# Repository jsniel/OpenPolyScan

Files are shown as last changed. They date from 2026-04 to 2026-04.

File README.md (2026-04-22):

# OpenPolyScan

OpenPolyScan est un prototype open source de reconnaissance de plastiques à bas coût,
conçu pour des usages en fablabs, ateliers, médiation, recherche-action et expérimentation locale.

Le projet repose sur :
- un capteur multispectral **AS7265x**
- une carte **ESP32** pour l’acquisition et l’export des mesures
- un jeu de données spectral
- des scripts Python de classification par apprentissage automatique

---

## Origine du projet

OpenPolyScan a été initié au sein de **L’Atelier Autonome** dans le cadre d’un projet de
recyclage local du plastique inspiré de Precious Plastic, soutenu par l’ADEME dans l’appel
à projets « Low-tech en territoire normand ».

Il est publié en open source afin d’en assurer la continuité et la diffusion.
Le projet est désormais maintenu par **Jean-Sébastien Niel**.

L’objectif était de développer un appareil simple et accessible d’identification des plastiques
pour des structures comme les fablabs et ateliers citoyens.

---

## Objectifs

- rendre visible et compréhensible l’analyse spectrale des plastiques  
- proposer une base reproductible à faible coût  
- documenter un prototype technique ouvert  
- ouvrir la voie à une base de données collaborative de signatures spectrales  
- permettre à d’autres ateliers, chercheurs ou structures pédagogiques d’améliorer le projet  

---

## Contenu du dépôt

- `firmware/` : code ESP32 pour l’acquisition et l’export CSV  
- `scripts/` : scripts Python d’entraînement et d’évaluation  
- `data/` : jeux de données spectrales d’exemple  
- `hardware/` : fichiers CAO et STL du support / boîtier  
- `docs/` : documentation technique et méthodologique  
- `models/` : emplacement pour les modèles entraînés  
- `examples/` : exemples d’utilisation  

---

## État du projet

OpenPolyScan est un **prototype expérimental**.

Le système permet :
- d’acquérir des mesures spectrales  
- de constituer un jeu de données  
- d’entraîner des modèles de classification  

⚠️ Ce projet **n’est pas un outil industriel**.  
Les performances dépendent fortement :
- du protocole de mesure  
- de la taille du dataset  
- de la diversité des plastiques  
- des conditions d’acquisition  

---

## Matériel principal

- capteur SparkFun Triad / AS7265x  
- carte ESP32  
- support mécanique imprimé en 3D  

---

## Aperçu du système

### Prototype

<p align="center">
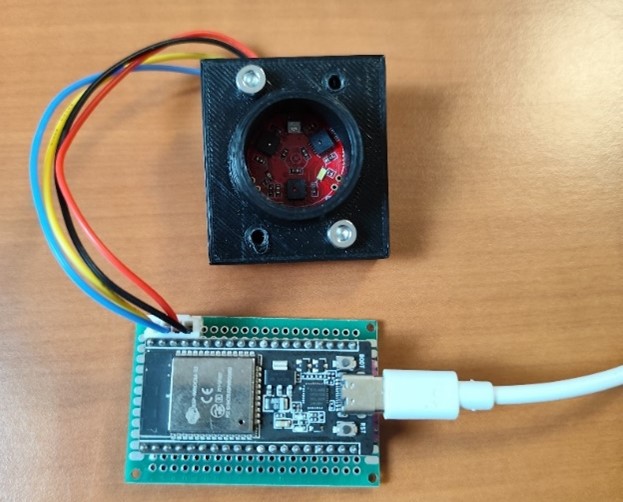
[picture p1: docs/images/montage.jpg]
  
</p>

### Interface web embarquée

<p align="center">
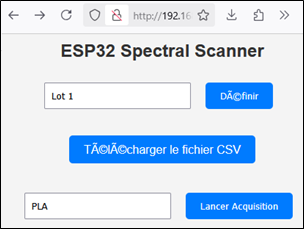
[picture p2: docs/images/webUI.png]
  
</p>

---

## Données actuelles

Le dépôt contient un premier jeu de données avec :
- PLA  
- PP  
- HDPE  

Ce dataset est fourni comme base d’expérimentation.

---

## Prise en main rapide

### 1. Installation

#### Linux / macOS
```bash
python3 -m venv .venv
source .venv/bin/activate
pip install -r scripts/requirements.txt
```

#### Windows PowerShell
```powershell
python -m venv .venv
.venv\Scripts\Activate.ps1
pip install -r scripts\requirements.txt
```

### 2. Entraîner un modèle

```bash
python scripts/train_plastic_model.py --file data/raw/dataset.csv
```

### 3. Tester différents modèles

```bash
python scripts/classif_spectre.py --file data/raw/dataset.csv
```

---

## Référence scientifique

Ce projet s’inspire notamment de :

Martinez-Hernandez, U.; West, G.; Assaf, T.  
*Low-Cost Recognition of Plastic Waste Using Deep Learning and a Multi-Spectral Near-Infrared Sensor.*  
Sensors 2024, 24, 2821.  
DOI: 10.3390/s24092821  

---

## Licences

Ce dépôt utilise plusieurs licences selon la nature des contenus :

- **Code source** (`firmware/`, `scripts/`) → AGPL-3.0-or-later  
- **Hardware** (`hardware/`) → CERN-OHL-S-2.0  
- **Documentation** → CC BY-SA 4.0  
- **Données** → CC BY-SA 4.0 (sauf mention contraire)  

Voir `LICENSE.md` pour plus de détails.

---

## Auteurs

Voir `AUTHORS.md`.

---

## Contribuer

Les contributions sont bienvenues :

- amélioration du firmware  
- enrichissement du dataset  
- amélioration des modèles  
- ajout de nouveaux plastiques  
- amélioration de la documentation  

---

## Vision

OpenPolyScan vise à devenir une **base ouverte et collaborative**
pour l’analyse spectrale des plastiques à faible coût.

Toute contribution permettant d’améliorer :
- la qualité des données  
- la reproductibilité  
- la compréhension des résultats  

est encouragée.

---

## Dépôt

Projet maintenu sur GitHub :
https://github.com/jsniel/openpolyscan

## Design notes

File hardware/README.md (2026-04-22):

Hardware files.
# Hardware

Ce dossier contient les fichiers matériels du prototype OpenPolyScan.

## Contenu

- `cad/` : fichiers FreeCAD paramétriques
- `stl/` : exports STL imprimables

## Fonction

Ces fichiers permettent de fabriquer ou modifier le support mécanique du capteur
et les éléments imprimés associés au prototype.

## Licence

Les fichiers matériels sont publiés sous licence **CERN-OHL-S-2.0**.

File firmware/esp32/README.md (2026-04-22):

# OpenPolyScan — Firmware ESP32

Ce dossier contient le firmware utilisé pour l’acquisition des données spectrales
dans le projet OpenPolyScan.

Le firmware permet :
- de piloter un capteur multispectral **AS7265x (SparkFun Triad)**
- de mesurer des signatures spectrales
- d’exposer une interface web locale
- d’exporter les données au format CSV

---

## ⚙️ Matériel nécessaire

- ESP32 (type DevKit)
- Capteur **SparkFun Triad AS7265x**
- Connexion I2C (SDA / SCL)
- Alimentation USB

---

## 🔌 Connexions

| ESP32 | AS7265x |
|---|---|
| 3.3V | VCC |
| GND  | GND |
| SDA  | SDA |
| SCL  | SCL |

⚠️ Vérifier que le capteur fonctionne en **3.3V**

---

## 🧠 Principe de fonctionnement

Le firmware :

1. Initialise le capteur AS7265x
2. Crée un point d’accès WiFi local (ESP32)
3. Lance un serveur web embarqué
4. Permet :
   - de déclencher des mesures
   - de visualiser les données
   - de télécharger un fichier CSV

---

## 📡 Connexion au système

1. Allumer l’ESP32
2. Se connecter au WiFi créé par l’ESP32

Par défaut :
   - SSID : OpenPolyScan
   - Password : atelierautonome

3. Ouvrir un navigateur
4. Aller à l’adresse :

http://192.168.4.1

---

## 🌐 Interface Web

L’interface permet :

- de lancer des mesures
- de visualiser les valeurs spectrales
- de générer un fichier CSV
- de télécharger les données

---

## Interface web

L’ESP32 expose une interface web accessible depuis un navigateur.

### Exemple d’interface

<p align="center">
  
</p>

---

## Format des données

Les données sont exportées sous forme de CSV :

- première colonne : label (matière)
- colonnes suivantes : intensités spectrales

Exemple :

PLA;0,82;0,76;0,65;...
PP;0,45;0,50;0,60;...

---

## Installation du firmware

### 1. Installer Arduino IDE

https://www.arduino.cc/en/software

---

### 2. Ajouter le support ESP32

Dans Arduino IDE :

- Fichier → Préférences
- Ajouter dans “URL de gestionnaire de cartes” :

https://dl.espressif.com/dl/package_esp32_index.json

Puis :

- Outils → Type de carte → Gestionnaire de cartes
- Installer **ESP32**

---

### 3. Installer les bibliothèques nécessaires

Dans le gestionnaire de bibliothèques :

- SparkFun AS7265x
- WiFi
- WebServer (inclus avec ESP32)

---

### 4. Charger le firmware

1. Ouvrir :
ESP32LocalCSVWebGenerator.ino

2. Sélectionner la carte ESP32
3. Sélectionner le port série
4. Cliquer sur Upload

---

## Configuration (optionnelle)

Dans le code, tu peux modifier :

- le nom du réseau WiFi
- les paramètres d’acquisition
- le format CSV

---

## Acquisition de données

### Étapes recommandées

1. Préparer un échantillon de plastique
2. Placer le capteur à distance constante
3. Limiter la lumière ambiante
4. Lancer plusieurs mesures
5. Télécharger le CSV
6. Ajouter le label (PLA, PP, etc.)

---

## Bonnes pratiques

- Toujours garder la même géométrie de mesure
- Nettoyer les échantillons
- Éviter les surfaces trop réfléchissantes
- Répéter les mesures

---

## Dépannage

### Le WiFi n’apparaît pas
- Vérifier que l’ESP32 est alimenté
- Redémarrer la carte

### Impossible d’accéder à la page web
- Vérifier que tu es connecté au bon WiFi
- Utiliser l’adresse 192.168.4.1

### Pas de données du capteur
- Vérifier les connexions I2C
- Vérifier l’alimentation
- Tester avec un exemple SparkFun

---

## 📜 Licence

Le firmware est publié sous licence :

AGPL-3.0-or-later

Voir le fichier LICENSE.md à la racine du projet.

---

## Contribution

Les contributions sont bienvenues :

- amélioration de l’interface web
- optimisation des mesures
- amélioration du format de données
- ajout de nouvelles fonctionnalités

---

## Contexte

Ce firmware fait partie du projet OpenPolyScan,
un système open source d’identification de plastiques à bas coût.

Projet initié par L’Atelier Autonome  
Maintenu par Jean-Sébastien Niel

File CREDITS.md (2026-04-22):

# Crédits

## Communauté d’inspiration

OpenPolyScan s’inscrit dans une démarche de fabrication ouverte, de recyclage distribué
et de réappropriation technique inspirée notamment par la communauté **Precious Plastic**.

## Inspiration scientifique

Ce projet s’inspire notamment des travaux suivants :

Martinez-Hernandez, U.; West, G.; Assaf, T.
**Low-Cost Recognition of Plastic Waste Using Deep Learning and a Multi-Spectral Near-Infrared Sensor**.
Sensors 2024, 24, 2821.
DOI: 10.3390/s24092821

L’article est publié en accès ouvert sous licence **CC BY 4.0**.

## Contexte du projet

Le projet a été développé initialement dans le cadre d’une expérimentation portée par
L’Atelier Autonome autour du recyclage local du plastique, avec le soutien de l’ADEME.

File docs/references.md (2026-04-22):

# Références

## Référence scientifique principale

Martinez-Hernandez, U.; West, G.; Assaf, T.
Low-Cost Recognition of Plastic Waste Using Deep Learning and a Multi-Spectral Near-Infrared Sensor.
Sensors 2024, 24, 2821.
DOI: 10.3390/s24092821

## Références de contexte

- communauté Precious Plastic
- documentation SparkFun AS7265x
- documentation ESP32
- documentation scikit-learn

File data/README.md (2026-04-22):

# Données

## Jeu de données principal

`raw/24_11_2025_PLA_PP_HDPE.csv`

## Description

Ce fichier contient des mesures spectrales acquises avec un capteur AS7265x.
La première colonne correspond au label matière.
Les colonnes suivantes correspondent aux bandes spectrales mesurées.

## Classes présentes

- PLA
- PP
- HDPE

## Format

- séparateur : `;`
- décimales : `,`

## Usage

Ce jeu de données sert de base d’expérimentation pour :
- l’entraînement de modèles simples
- l’évaluation comparative de classifieurs
- la documentation du protocole OpenPolyScan

## Limites

- taille encore modeste
- seulement trois familles de plastiques
- variabilité encore limitée des échantillons
- performances dépendantes du protocole d’acquisition

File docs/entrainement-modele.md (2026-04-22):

# Entraînement du modèle

## Pré-requis

- Python 3
- environnement virtuel recommandé
- dépendances listées dans `scripts/requirements.txt`

## Script principal

Le script `train_plastic_model.py` :
- charge un CSV
- effectue une validation croisée
- entraîne un RandomForest et un MLP
- affiche les rapports de classification
- sauvegarde un modèle au format `joblib`

## Script complémentaire

Le script `classif_spectre.py` :
- compare plusieurs classifieurs
- affiche une matrice de confusion
- propose une visualisation PCA

## Remarque importante

Les résultats obtenus dans OpenPolyScan sont directement liés :
- à la taille du jeu de données
- au choix des classes
- à la stabilité du protocole
- au nettoyage du dataset

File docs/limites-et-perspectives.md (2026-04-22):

# Limites et perspectives

## Limites actuelles

- jeu de données encore restreint
- nombre limité de types de plastiques
- sensibilité aux conditions expérimentales
- absence d’un protocole totalement stabilisé et standardisé
- prototype non destiné à un usage industriel

## Pistes d’amélioration

- augmenter fortement le nombre d’échantillons
- ajouter de nouvelles classes (PET, LDPE, PVC, PS, etc.)
- enrichir les métadonnées (couleur, texture, épaisseur, provenance)
- améliorer la reproductibilité mécanique du montage
- tester des modèles plus robustes
- embarquer à terme un modèle léger sur microcontrôleur ou dispositif autonome

## Vision long terme

OpenPolyScan a vocation à devenir une base collaborative :
- pour mutualiser des jeux de données
- pour partager des protocoles de mesure
- pour documenter des variantes matérielles
- pour améliorer progressivement les performances du système

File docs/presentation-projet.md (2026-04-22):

# Présentation du projet

OpenPolyScan est un projet de reconnaissance de plastiques à bas coût,
pensé pour des usages de recherche-action, de médiation, de fablab et d’expérimentation.

Le projet a été initié au sein de L’Atelier Autonome dans le cadre d’un travail plus large
autour du recyclage local du plastique, de la pédagogie technique et de la mutualisation
de solutions ouvertes.

L’idée centrale est de proposer un système simple et accessible permettant d’explorer
la reconnaissance de plastiques à partir de signatures spectrales mesurées par un capteur
multispectral de type AS7265x.

OpenPolyScan ne prétend pas remplacer les équipements industriels de tri.
Il propose une base expérimentale reproductible, documentée et améliorable.

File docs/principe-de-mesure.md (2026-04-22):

# Principe de mesure

Le système repose sur l’idée que différents plastiques présentent des réponses différentes
lorsqu’ils sont éclairés.

Le capteur AS7265x mesure l’intensité lumineuse réfléchie sur 18 longueurs d’onde,
du visible au proche infrarouge.

Chaque échantillon produit ainsi une signature spectrale.
Ces mesures peuvent ensuite être utilisées comme variables d’entrée pour entraîner
un modèle de classification.

Dans OpenPolyScan, l’acquisition est réalisée via une carte ESP32, puis les données
sont exportées en CSV pour analyse.

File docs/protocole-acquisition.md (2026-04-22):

# Protocole d’acquisition

## Objectif

Obtenir des mesures spectrales aussi comparables que possible entre différents échantillons.

## Recommandations générales

- utiliser une géométrie de mesure stable
- maintenir une distance capteur / échantillon constante
- limiter les variations de lumière ambiante
- utiliser des échantillons propres et si possible relativement plats
- documenter la matière, la couleur, l’origine et l’état de surface

## Bonnes pratiques

- répéter les mesures pour chaque matériau
- conserver le même protocole pour toutes les classes
- noter toute anomalie ou doute sur l’échantillon
- séparer clairement données d’apprentissage et nouvelles données de test

## Limites

Les performances d’un modèle dépendent fortement :
- de la régularité du protocole
- de la qualité des labels
- de la diversité des échantillons

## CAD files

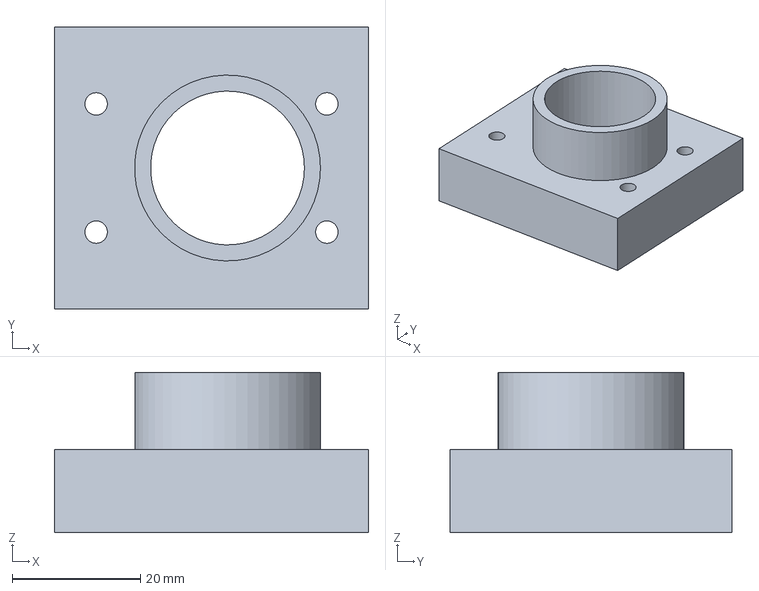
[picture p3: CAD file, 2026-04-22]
hardware/cad/Sparkfuntriad3.FCStd
49.0 x 44.0 x 25.0 mm

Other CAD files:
hardware/stl/Sparkfuntriad3-Body.stl

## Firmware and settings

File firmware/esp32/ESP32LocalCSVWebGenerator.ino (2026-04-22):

// Copyright (c) 2024-2026 Atelier Autonome & Jean-Sébastien Niel
// SPDX-License-Identifier: AGPL-3.0-or-later

#include "SparkFun_AS7265X.h"
#include "SPIFFS.h"
#include <WiFi.h>
#include <WebServer.h>

AS7265X sensor;
WebServer server(80);

const char *ssid = "OpenPolyScan";
const char *password = "atelierautonome";

String fileName = "/default.csv";
String lastLabel = "";  
bool acquisitionRequested = false;  

void writeToCSV(String label, float values[]) {
  File file = SPIFFS.open(fileName, FILE_APPEND);
  if (!file) {
    Serial.println("Erreur d'ouverture du fichier CSV !");
    return;
  }

  for (int i = 0; i < 18; i++) {
    file.print(values[i]);
    file.print(",");
  }
  file.println(label);  
  file.close();
  Serial.println("Données enregistrées !");
}

void takeMeasurement() {
  Serial.println("Acquisition en cours...");
  sensor.takeMeasurements();  

  float values[18] = {
    sensor.getCalibratedA(), sensor.getCalibratedB(), sensor.getCalibratedC(),
    sensor.getCalibratedD(), sensor.getCalibratedE(), sensor.getCalibratedF(),
    sensor.getCalibratedG(), sensor.getCalibratedH(), sensor.getCalibratedR(),
    sensor.getCalibratedI(), sensor.getCalibratedS(), sensor.getCalibratedJ(),
    sensor.getCalibratedT(), sensor.getCalibratedU(), sensor.getCalibratedV(),
    sensor.getCalibratedW(), sensor.getCalibratedK(), sensor.getCalibratedL()
  };

  writeToCSV(lastLabel, values);
  Serial.println("Acquisition terminée !");
}

void handleDownload() {
  Serial.println("Requête de téléchargement reçue !");
  
  File file = SPIFFS.open(fileName, FILE_READ);
  if (!file) {
    server.send(404, "text/plain", "Fichier non trouvé");
    return;
  }

  Serial.println("Envoi du fichier CSV...");
  server.sendHeader("Content-Type", "text/csv");
  server.sendHeader("Content-Disposition", "attachment; filename=" + fileName);
  server.sendHeader("Connection", "close");
  server.streamFile(file, "text/csv");
  
  file.close();
  Serial.println("Fichier envoyé !");
}

void handleRoot() {
  String html = "<html><head><title>ESP32 Spectral Scanner</title>";
  html += "<style>";
  html += "body { font-family: Arial, sans-serif; text-align: center; background-color: #f4f4f4; }";
  html += "h2 { color: #333; }";
  html += "a, input[type=submit] { display: inline-block; padding: 10px 20px; margin: 10px; text-decoration: none; color: white; background: #007BFF; border-radius: 5px; border: none; }";
  html += "a:hover, input[type=submit]:hover { background: #0056b3; }";
  html += "form { margin-top: 20px; }";
  html += "input[type=text] { padding: 8px; width: 200px; margin-right: 10px; }";
  html += "</style></head><body>";
  html += "<h2>ESP32 Spectral Scanner</h2>";

  html += "<form action='/setfile' method='GET'>";
  html += "<input type='text' name='filename' placeholder='Nom du fichier CSV'>";
  html += "<input type='submit' value='Définir'>";
  html += "</form>";

  html += "<a href='/download'>Télécharger le fichier CSV</a>";

  html += "<form action='/acquire' method='GET'>";
  html += "<input type='text' name='label' placeholder='Entrez un label'>";
  html += "<input type='submit' value='Lancer Acquisition'>";
  html += "</form></body></html>";

  server.send(200, "text/html", html);
}

void handleSetFile() {
  if (server.hasArg("filename")) {
    fileName = "/" + server.arg("filename") + ".csv";
    Serial.println("Fichier CSV défini via Web : " + fileName);

    File file = SPIFFS.open(fileName, FILE_WRITE);
    if (!file) {
      Serial.println("Erreur création fichier !");
    } else {
      file.println("410nm,435nm,460nm,485nm,510nm,535nm,560nm,585nm,610nm,645nm,680nm,705nm,730nm,760nm,810nm,860nm,900nm,940nm,Label");
      file.close();
      Serial.println("Fichier CSV initialisé !");
    }

    server.send(200, "text/plain", "Fichier défini : " + fileName);
  } else {
    server.send(400, "text/plain", "Nom de fichier non fourni !");
  }
}

void handleAcquire() {
  if (server.hasArg("label")) {
    lastLabel = server.arg("label");
    acquisitionRequested = true;  
    Serial.println("Acquisition demandée pour : " + lastLabel);
    server.send(200, "text/plain", "Acquisition en cours...");
  } else {
    server.send(400, "text/plain", "Label non fourni !");
  }
}

void setup() {
  Serial.begin(115200);
  Serial.println("Démarrage...");

  if (!SPIFFS.begin(true)) {
    Serial.println("Erreur SPIFFS !");
    return;
  }

  if (sensor.begin() == false) {
    Serial.println("Capteur non détecté !");
    while (1);
  }

  WiFi.softAP(ssid, password);
  Serial.print("AP démarré : ");
  Serial.println(ssid);
  Serial.println("Accédez à http://192.168.4.1/");

  server.on("/", handleRoot);
  server.on("/download", handleDownload);
  server.on("/setfile", handleSetFile);
  server.on("/acquire", handleAcquire);
  server.begin();
  Serial.println("Serveur Web actif !");

  Serial.println("Entrez le nom du fichier CSV à créer (optionnel) :");
}

void loop() {
  server.handleClient();  

  if (Serial.available()) {
    String input = Serial.readStringUntil('\n');
    input.trim();

    if (fileName == "/default.csv") {  
      fileName = "/" + input + ".csv";
      Serial.println("Fichier CSV défini via Série : " + fileName);

      File file = SPIFFS.open(fileName, FILE_WRITE);
      if (!file) {
        Serial.println("Erreur création fichier !");
      } else {
        file.println("410nm,435nm,460nm,485nm,510nm,535nm,560nm,585nm,610nm,645nm,680nm,705nm,730nm,760nm,810nm,860nm,900nm,940nm,Label");
        file.close();
        Serial.println("Fichier CSV initialisé !");
      }
    } else {  
      lastLabel = input;
      Serial.println("Acquisition demandée via Série pour : " + lastLabel);
      acquisitionRequested = true;
    }
  }

  if (acquisitionRequested) {
    acquisitionRequested = false;  
    takeMeasurement();
  }
}

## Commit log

2026-04-22 Initial release of OpenPolyScan
    [24_11_2025_PLA_PP_HDPE.csv, Sparkfuntriad3-Body.stl, Sparkfuntriad3.FCStd]
2026-04-22 Initial public release of OpenPolyScan project
    [24_11_2025_PLA_PP_HDPE.csv]
